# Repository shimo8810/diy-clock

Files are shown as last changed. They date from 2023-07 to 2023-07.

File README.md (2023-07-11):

# Rust Board

## Purpose

This project is intended for my personal study and information sharing. The main objectives are as follows:

### Practicing Electronics Circuit

Being a complete novice in circuit design, I created a simple hobby board for the purpose of studying circuit and PCB design.

### Gathering Information on Embedded Rust

The knowledge of developing embedded systems using Rust are scattered, so I wanted to compile information for myself. While there is a wealth of development information available for well-known boards, there is limited knowledge on directly controlling microcontrollers.

## Electronics Circuit

PCB 3D

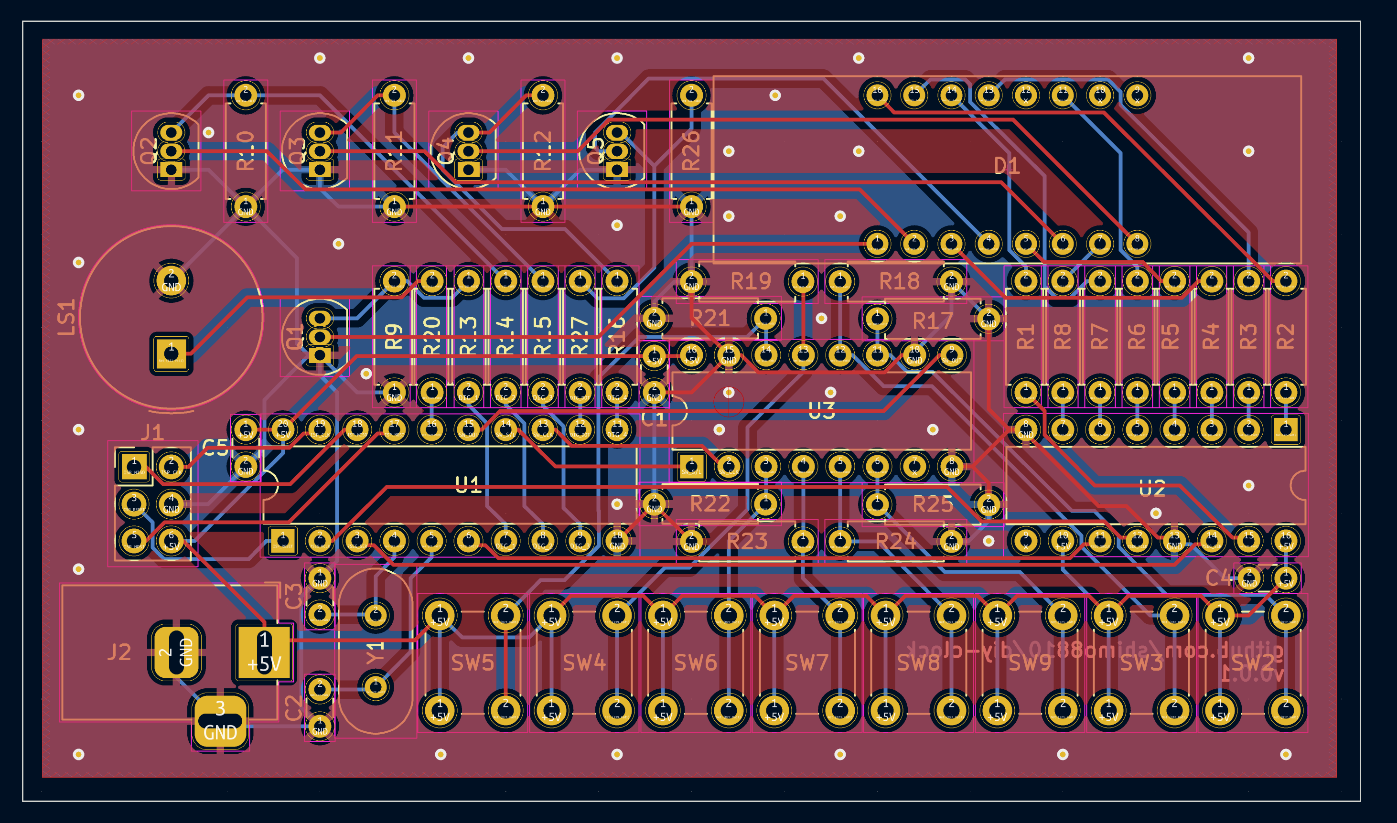
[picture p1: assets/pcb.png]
PCB


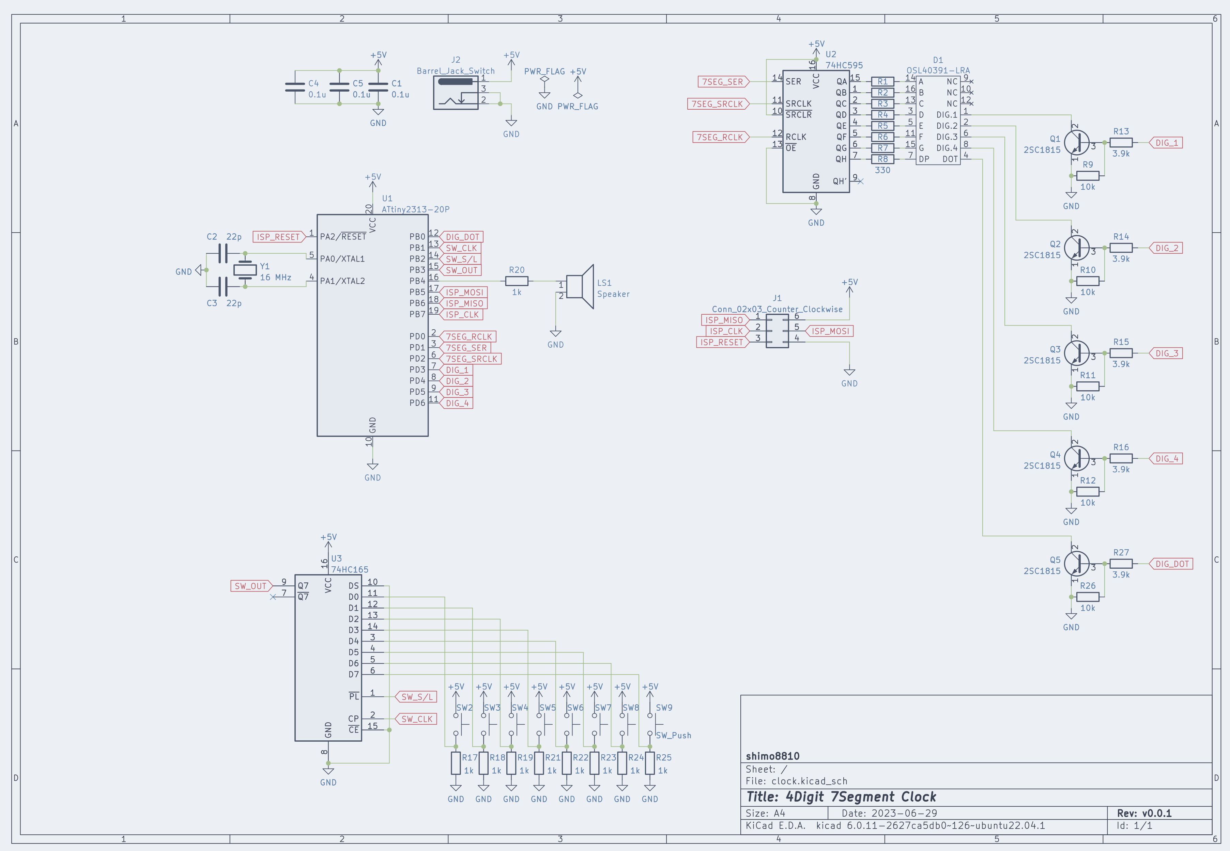
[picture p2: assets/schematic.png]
schematic


## FirmWare

### connection

In this project, I use FT232RL to write firmware to this board. The connection between FT232RL and the clock's ISP pins should be made according to the table below. Please note that the current version has a design flaw in the ISP pin layout, which deviates from the standard ISP pin configuration. It has become confusing and inconvenient due to this misleading and unfortunate design. Therefore, caution should be exercised.

| FT232RL | PIN |
| :-----: | :---: |
| CTS | ISP_MISO  |
| DCD | ISP_MOSI  |
| DSR |  ISP_SCK  |
| RI | ISP_RESET |
| VCC | 5V |
| GND | GND |

### writing

I use avrdude for writing the firmware. Writing can be performed with the following command. When writing for the first time, it is necessary to configure the fuse settings for attiny2313. Since we are running attiny2313 with an external oscillator (16MHz) and no prescaler, please write with the following settings.

```sh
avrdude -c diecimila \
        -p t2313 \
        -U flash:w:./target/avr-attiny2313/release/blink-attiny2313.elf:e \
        -U lfuse:w:0xff:m
```

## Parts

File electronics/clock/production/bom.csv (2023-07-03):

Designator | Footprint | Quantity | Value | LCSC Part #
C1, C4, C5 | C_Disc_D3.0mm_W1.6mm_P2.50mm | 3 | 0.1u
C2, C3 | C_Disc_D3.0mm_W1.6mm_P2.50mm | 2 | 22p
D1 | OSL40391-LRA | 1 | OSL40391-LRA
J1 | PinHeader_2x03_P2.54mm_Vertical | 1 | Conn_02x03_Counter_Clockwise
J2 | BarrelJack_Horizontal | 1 | Barrel_Jack_Switch
LS1 | Buzzer_TDK_PS1240P02BT_D12.2mm_H6.5mm | 1 | Speaker
Q1, Q2, Q3, Q4, Q5 | TO-92_Inline | 5 | 2SC1815
R1, R2, R3, R4, R5, R6, R7, R8 | R_Axial_DIN0207_L6.3mm_D2.5mm_P7.62mm_Horizontal | 8 | 330
R10, R11, R12, R26, R9 | R_Axial_DIN0207_L6.3mm_D2.5mm_P7.62mm_Horizontal | 5 | 10k
R13, R14, R15, R16, R27 | R_Axial_DIN0207_L6.3mm_D2.5mm_P7.62mm_Horizontal | 5 | 3.9k
R17, R18, R19, R20, R21, R22, R23, R24, R25 | R_Axial_DIN0207_L6.3mm_D2.5mm_P7.62mm_Horizontal | 9 | 1k
SW2, SW3, SW4, SW5, SW6, SW7, SW8, SW9 | SW_PUSH_6mm_H5mm | 8 | SW_Push
U1 | DIP-20_W7.62mm | 1 | ATtiny2313-20P
U2 | DIP-16_W7.62mm | 1 | 74HC595
U3 | DIP-16_W7.62mm | 1 | 74HC165
Y1 | Crystal_HC18-U_Vertical | 1 | 16 MHz

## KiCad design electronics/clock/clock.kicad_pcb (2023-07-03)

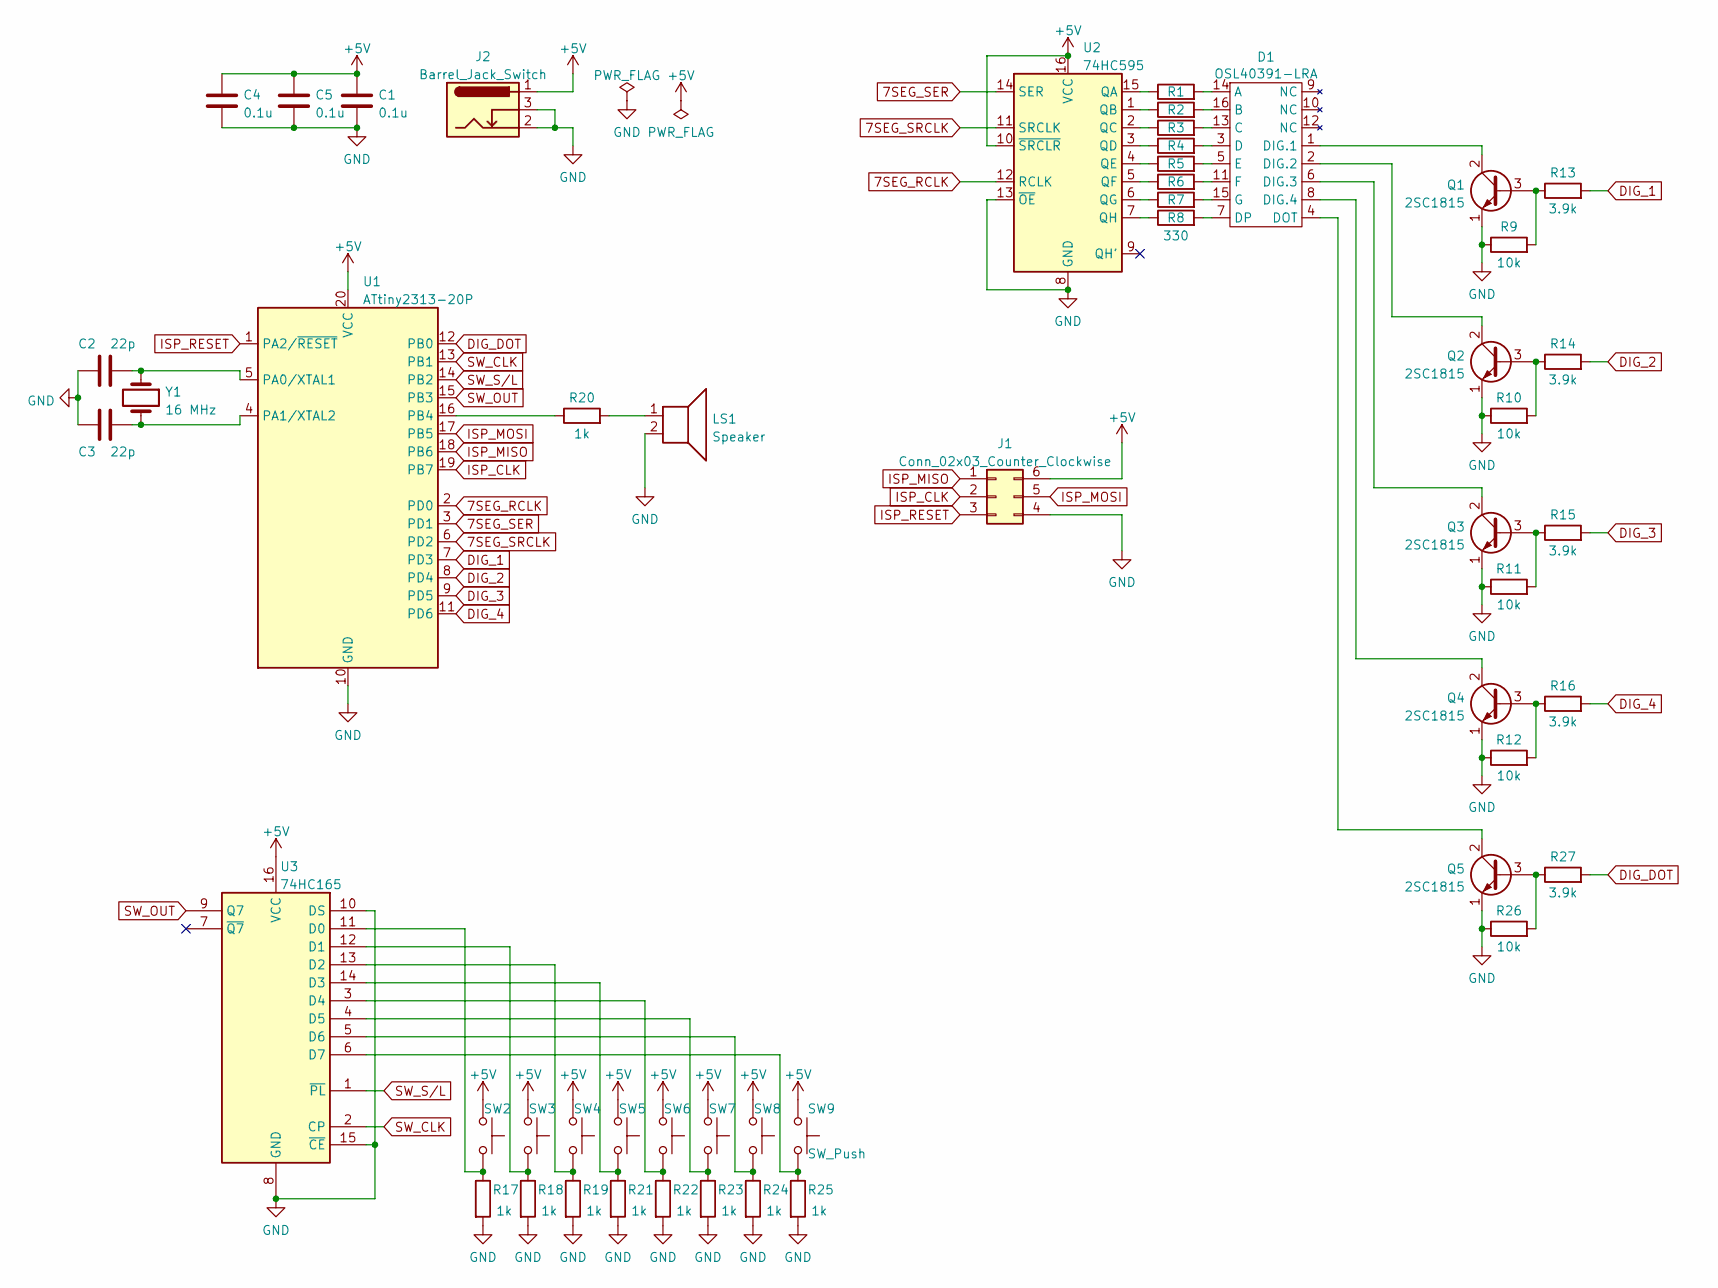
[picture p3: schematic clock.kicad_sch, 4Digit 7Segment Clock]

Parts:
C1, C4, C5: 0.1u; C_Disc_D3.0mm_W1.6mm_P2.50mm
C2, C3: 22p; C_Disc_D3.0mm_W1.6mm_P2.50mm
D1: OSL40391-LRA
J1: Conn_02x03_Counter_Clockwise; PinHeader_2x03_P2.54mm_Vertical
J2: Barrel_Jack_Switch; BarrelJack_Horizontal
LS1: Speaker; Buzzer_TDK_PS1240P02BT_D12.2mm_H6.5mm
Q1, Q2, Q3, Q4, Q5: 2SC1815; TO-92_Inline
R1, R2, R3, R4, R5, R6, R7, R8: 330; R_Axial_DIN0207_L6.3mm_D2.5mm_P7.62mm_Horizontal
R9, R10, R11, R12, R26: 10k; R_Axial_DIN0207_L6.3mm_D2.5mm_P7.62mm_Horizontal
R13, R14, R15, R16, R27: 3.9k; R_Axial_DIN0207_L6.3mm_D2.5mm_P7.62mm_Horizontal
R17, R18, R19, R20, R21, R22, R23, R24, R25: 1k; R_Axial_DIN0207_L6.3mm_D2.5mm_P7.62mm_Horizontal
SW2, SW3, SW4, SW5, SW6, SW7, SW8, SW9: SW_Push; SW_PUSH_6mm_H5mm
U1: ATtiny2313-20P; DIP-20_W7.62mm
U2: 74HC595; DIP-16_W7.62mm
U3: 74HC165; DIP-16_W7.62mm
Y1: 16 MHz; Crystal_HC18-U_Vertical

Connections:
7SEG_RCLK: U1.2 (PD0), U2.12 (RCLK)
7SEG_SER: U1.3 (PD1), U2.14 (SER)
7SEG_SRCLK: U1.6 (PD2), U2.11 (SRCLK)
+5V: C1.1, C4.1, C5.1, J1.6, J2.1, SW2.1, SW3.1, SW4.1, SW5.1, SW6.1, SW7.1, SW8.1, SW9.1, U1.20 (VCC), U2.10 (~SRCLR), U2.16 (VCC), U3.16 (VCC)
DIG_1: R13.2, U1.7 (PD3)
DIG_2: R14.2, U1.8 (PD4)
DIG_3: R15.2, U1.9 (PD5)
DIG_4: R16.2, U1.11 (PD6)
DIG_DOT: R27.2, U1.12 (PB0)
GND: C1.2, C2.1, C3.1, C4.2, C5.2, J1.4, J2.2, J2.3, LS1.2, Q1.1 (E), Q2.1 (E), Q3.1 (E), Q4.1 (E), Q5.1 (E), R9.1, R10.1, R11.1, R12.1, R17.2, R18.2, R19.2, R21.2, R22.2, R23.2, R24.2, R25.2, R26.1, U1.10 (GND), U2.8 (GND), U2.13 (~OE), U3.8 (GND), U3.10 (DS), U3.15 (~CE)
ISP_CLK: J1.2, U1.19 (PB7)
ISP_MISO: J1.1, U1.18 (PB6)
ISP_MOSI: J1.5, U1.17 (PB5)
ISP_RESET: J1.3, U1.1 (PA2/~RESET)
unnamed: C2.2, U1.5 (PA0/XTAL1), Y1.1
unnamed: C3.2, U1.4 (PA1/XTAL2), Y1.2
unnamed: D1.1 (DIG.1), Q1.2 (C)
unnamed: D1.2 (DIG.2), Q2.2 (C)
unnamed: D1.3 (D), R4.2
unnamed: D1.4 (DOT), Q5.2 (C)
unnamed: D1.5 (E), R5.2
unnamed: D1.6 (DIG.3), Q3.2 (C)
unnamed: D1.7 (DP), R8.2
unnamed: D1.8 (DIG.4), Q4.2 (C)
unnamed: D1.11 (F), R6.2
unnamed: D1.13 (C), R3.2
unnamed: D1.14 (A), R1.2
unnamed: D1.15 (G), R7.2
unnamed: D1.16 (B), R2.2
unnamed: LS1.1, R20.2
unnamed: Q1.3 (B), R9.2, R13.1
unnamed: Q2.3 (B), R10.2, R14.1
unnamed: Q3.3 (B), R11.2, R15.1
unnamed: Q4.3 (B), R12.2, R16.1
unnamed: Q5.3 (B), R26.2, R27.1
unnamed: R1.1, U2.15 (QA)
unnamed: R2.1, U2.1 (QB)
unnamed: R3.1, U2.2 (QC)
unnamed: R4.1, U2.3 (QD)
unnamed: R5.1, U2.4 (QE)
unnamed: R6.1, U2.5 (QF)
unnamed: R7.1, U2.6 (QG)
unnamed: R8.1, U2.7 (QH)
unnamed: R17.1, SW2.2, U3.11 (D0)
unnamed: R18.1, SW3.2, U3.12 (D1)
unnamed: R19.1, SW4.2, U3.13 (D2)
unnamed: R20.1, U1.16 (PB4)
unnamed: R21.1, SW5.2, U3.14 (D3)
unnamed: R22.1, SW6.2, U3.3 (D4)
unnamed: R23.1, SW7.2, U3.4 (D5)
unnamed: R24.1, SW8.2, U3.5 (D6)
unnamed: R25.1, SW9.2, U3.6 (D7)
SW_CLK: U1.13 (PB1), U3.2 (CP)
SW_OUT: U1.15 (PB3), U3.9 (Q7)
SW_S/L: U1.14 (PB2), U3.1 (~PL)

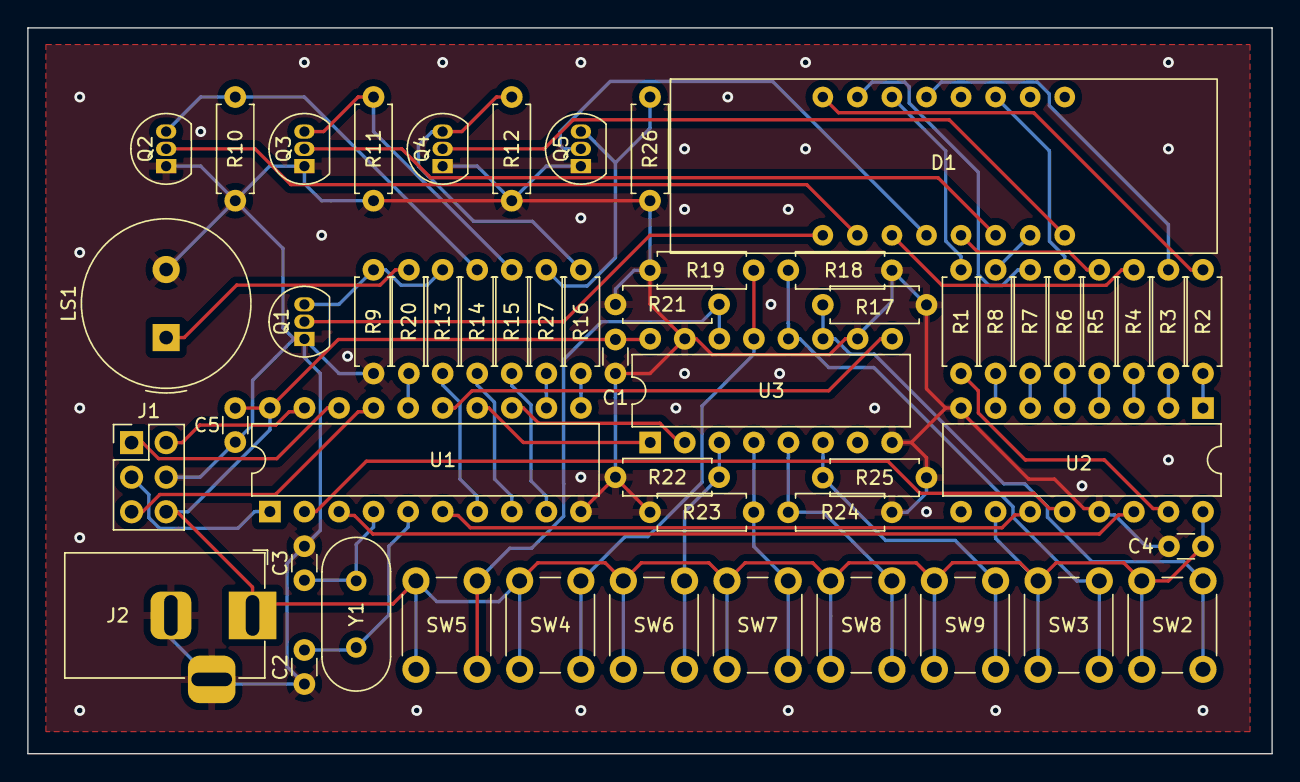
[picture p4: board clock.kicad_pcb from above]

Board: 2 copper layers, 91.4 x 53.3 mm, 53 parts (0 on the bottom side), 55 nets.

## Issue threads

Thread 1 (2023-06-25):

7seg部分の問題

shimo8810, 2023-06-25:
74HC595の出力電力は35mA, IC全体で75mA.
7seg. + 1dotの合計8個のLEDを同時に光らせることを考えると75mA / 8 = 9.375mA, これが流せる電流の最大になる.
明るさ的には5桁分をダイナミック点灯するので, 9.375 / 5 = 1.875mA相当, 少し暗くなる.

shimo8810, 2023-07-03:
各LEDで1mAで動作させたところ, 問題なく光っているので良し.
パーツごとのばらつきなどで暗くなる場合もあるかもしれない.

Closed 2023-07-03.

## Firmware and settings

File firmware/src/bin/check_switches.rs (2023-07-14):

#![no_std]
#![no_main]

use attiny_hal as hal;

use firmware::ssd;

use firmware::switches::{state2number, Edge, Switches};

#[hal::entry]
fn main() -> ! {
    let dp = hal::Peripherals::take().unwrap();
    let pins: hal::Pins = hal::pins!(dp);

    let mut ssd = ssd::Ssd::new(
        pins.pd0.into_output(),
        pins.pd1.into_output(),
        pins.pd2.into_output(),
        pins.pd3.into_output(),
        pins.pd4.into_output(),
        pins.pd5.into_output(),
        pins.pd6.into_output(),
        pins.pb0.into_output(),
    );
    ssd.light_off();

    let mut switches = Switches::new(
        pins.pb1.into_output(),
        pins.pb2.into_output(),
        pins.pb3.into_floating_input(),
    );

    loop {
        let state = switches.state(Edge::No);
        let number = state2number(&state) as usize;
        ssd.display_number(number, false);
    }
}

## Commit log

2023-06-22 [add] add i
    [clock.kicad_pcb, clock.kicad_sch]
2023-07-03 [update] v0.0.1を作成
    [bom.csv, clock.kicad_pcb, clock.kicad_sch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]
2023-07-09 [remove] removed arduino code
2023-07-11 chore: add avr-device crate
    to use timer interrupts, PAC-level access is required
2023-07-11 feat: implement time counting with timer interrupts
2023-07-14 feat: implement operation of tactile switch
2023-07-14 feat: add firmware to verify the operation of tactile switch
2023-07-14 feat: add switches and panic to the library
